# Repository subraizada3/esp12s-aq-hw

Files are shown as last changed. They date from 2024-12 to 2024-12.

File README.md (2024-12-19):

# ESP8266-based air quality sensor master board

This is a board that powers an ESP-12S module with USB-C, and has breakouts for I2C and UART.

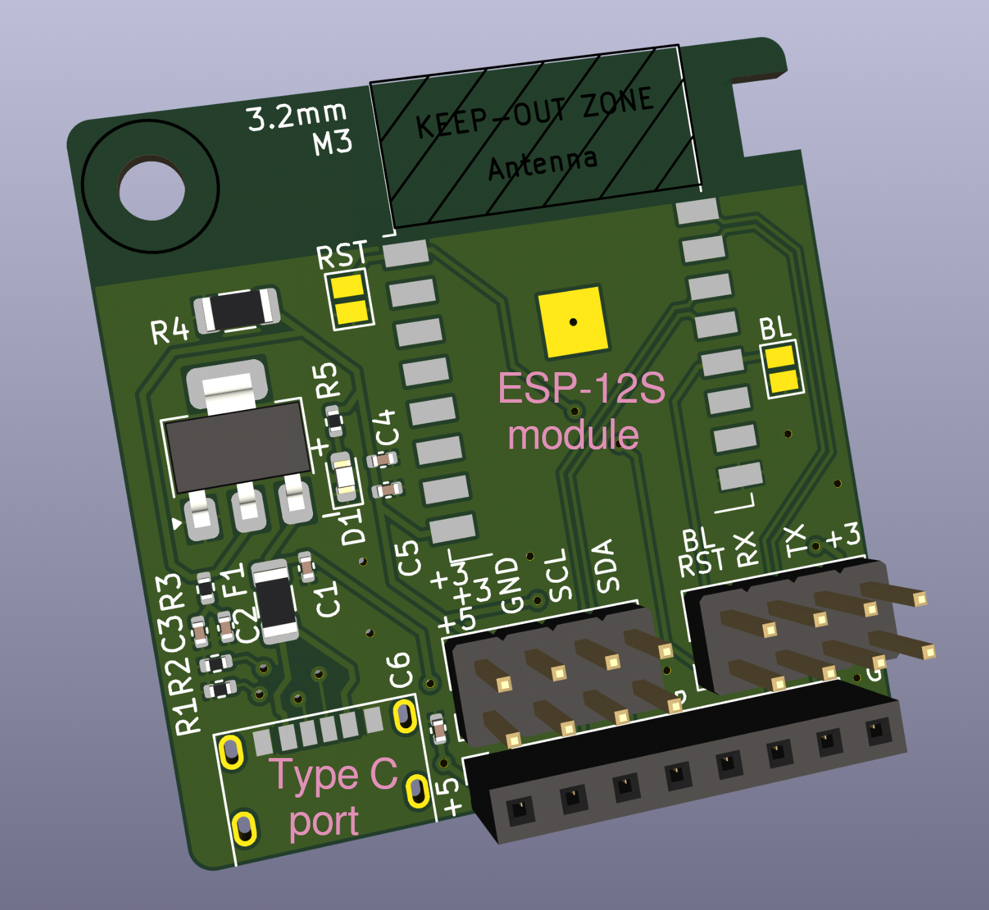
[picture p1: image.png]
image of board


Designed for use as an air quality sensor in combination with:

- Sensirion SCD41 (high accuracy NDIR CO2) - available on an I2C breakout board from various manufacturers
- Sensirion SGP40 (VOC) - available on an I2C breakout board from various manufacturers
- Sensirion SPS30 (particulate matter) - Sensirion manufactures an eval kit that comes with a cable, Sparkfun also sells their own similar kit

Though there's nothing really air-quality-specific here. This is a generic board that powers an ESP-12S and breaks out the I2C/UART pins + 5v/3.3v power to headers. Whatever you connect to those headers is up to you.

See [bom.ods](./bom.ods) for LCSC part numbers for this board (for PCB assembly by JLCPCB).

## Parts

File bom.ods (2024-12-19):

Comment | Qty | Designator | Footprint | Name | LCSC Part # | Extended | Note
USB-C port | 1 | J1 | USB-C-SMD_10P-P1.00-L6.8-W8.9 | TYPE-C-31-M-17 | C283540 | YES | Pins out to in are GND/Vbus/CC
3.3v regulator | 1 | U1 | SOT-223 | AMS1117-3.3 | C6186 | N | Top view, tab facing up, pins L-R are GND/Vout/Vin
ESP-12S | 1 | U2 | QFN-16_EP_16.0x24.0x2.0P | ESP-12S | C82898 | YES
Male header 2x4 | 2 | J2,J4 | Through hole | HDR-TH_8P-P2.54-V-R2-C4-S2.54 | C124386 | YES | 2.54mm, 1.02mm holes in PCB
Female headers 1x8 | 1 | J3 | Through hole | HDR-TH_8P-P2.54-V | C27438 | YES | 2.54mm, 1.02mm holes in PCB
Resistor 5.1k | 2 | R1,R2 | R0402 | 0402WGF5101TCE | C25905 | N | 5mW load, chose 1/16W (62.5mW)
Resistor 1k | 1 | R5 | R0402 | 0402WGF1001TCE | C11702 | N | 2mW load, chose 1/16W (62.5mW)
Resistor 270-330 | 1 | R4 | R1206 | 1206W4F3000T5E | C17887 | N | 40mW load, chose 1/4W (250mW)
Resistor 1 | 1 | R3 | R0402 | 0402WGF100KTCE | C25086 | N | 6mW load, chose 1/16W (62.5mW)
Capacitor 1uF | 2 | C1,C6 | C0402 | CL05A105KA5NQNC | C52923 | N
Capacitor 10uF | 2 | C2,C3,C4 | C0402 | CL05A106MQ5NUNC | C15525 | N
Capacitor 100nF | 1 | C5 | C0402 | CL05B104KO5NNNC | C1525 | N
LED | 1 | D1 | LED_0603 | KT-0603R | C2286 | N | Dot = negative (to GND)
Polyfuse 1A hold | 1 | F1 | F1206 | nSMD100-13.2V | C70081 | YES

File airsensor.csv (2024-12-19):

Reference | Quantity | Value | Footprint | Datasheet
C2 C3 C4 | 3 | 10uF | Capacitor_SMD:C_0402_1005Metric | ~
C5 | 1 | 0.1uF | Capacitor_SMD:C_0402_1005Metric | ~
C1 C6 | 2 | 1uF | Capacitor_SMD:C_0402_1005Metric | ~
D1 | 1 | LED | LED_SMD:LED_0603_1608Metric | ~
F1 | 1 | 1A hold | Fuse:Fuse_1206_3216Metric | ~
H1 H2 | 2 | MountingHole | MountingHole:MountingHole_2.7mm_M2.5 | ~
H3 | 1 | MountingHole | MountingHole:MountingHole_2.2mm_M2 | ~
J1 | 1 | TYPE-C-31-M-17 | footprints:TYPE-C-31-M-17
J2 | 1 | SCD41 CO2 / SGP40 VOC | Connector_PinHeader_2.54mm:PinHeader_2x04_P2.54mm_Vertical | ~
J3 | 1 | SPS30 PM | Connector_PinSocket_2.54mm:PinSocket_1x08_P2.54mm_Vertical | ~
J4 | 1 | TTL Serial | Connector_PinHeader_2.54mm:PinHeader_2x04_P2.54mm_Vertical | ~
JP1 | 1 | RST | Jumper:SolderJumper-2_P1.3mm_Open_Pad1.0x1.5mm | ~
JP2 | 1 | BL | Jumper:SolderJumper-2_P1.3mm_Open_Pad1.0x1.5mm | ~
R1 R2 | 2 | 5.1k | Resistor_SMD:R_0402_1005Metric | ~
R3 | 1 | 1 | Resistor_SMD:R_0402_1005Metric | ~
R4 | 1 | 270-330 | Resistor_SMD:R_1206_3216Metric | ~
R5 | 1 | 1k | Resistor_SMD:R_0402_1005Metric | ~
U1 | 1 | AMS1117-3.3 | Package_TO_SOT_SMD:SOT-223-3_TabPin2 | http://www.advanced-monolithic.com/pdf/ds1117.pdf
U2 | 1 | ESP-12S | footprints:ESP-12S

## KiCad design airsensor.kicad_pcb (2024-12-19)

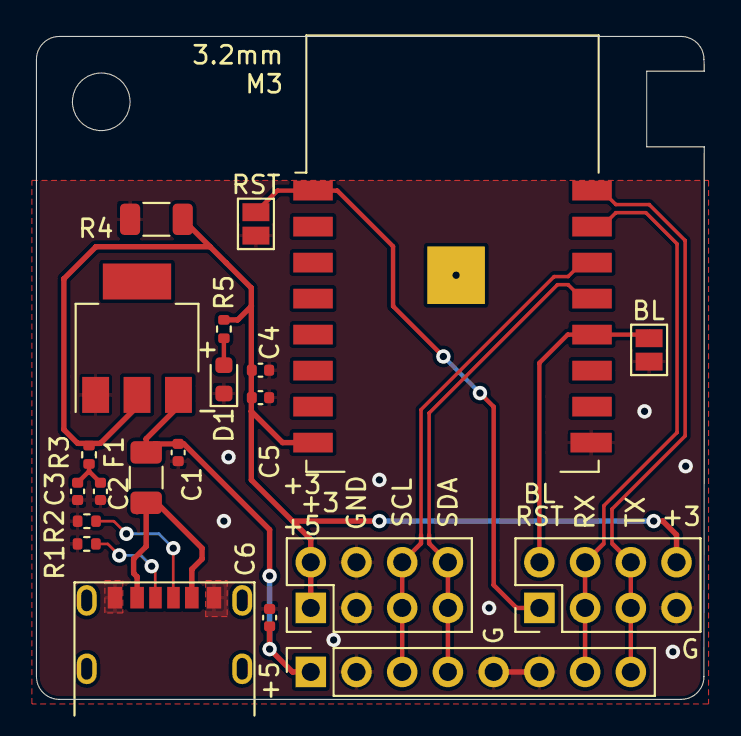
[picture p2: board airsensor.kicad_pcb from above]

Board: 2 copper layers, 37.1 x 36.8 mm, 22 parts (0 on the bottom side), 14 nets.

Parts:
C1, C6: 1uF; C_0402_1005Metric
C2, C3, C4: 10uF; C_0402_1005Metric
C5: 0.1uF; C_0402_1005Metric
D1: LED; LED_0603_1608Metric
F1: 1A hold; Fuse_1206_3216Metric
H1: M3; MountingHole_3.2mm_M3
J1: USB-C; M17
J2: SCD41 CO2 / SGP40 VOC; PinHeader_2x04_P2.54mm_Vertical
J3: SPS30 PM; PinSocket_1x08_P2.54mm_Vertical
J4: TTL Serial; PinHeader_2x04_P2.54mm_Vertical
JP1: RST; SolderJumper-2_P1.3mm_Open_Pad1.0x1.5mm
JP2: BL; SolderJumper-2_P1.3mm_Open_Pad1.0x1.5mm
R1, R2: 5.1k; R_0402_1005Metric
R3: 1; R_0402_1005Metric
R4: 270-330; R_1206_3216Metric
R5: 1k; R_0402_1005Metric
U1: AMS1117-3.3; SOT-223-3_TabPin2
U2: ESP-12S

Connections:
+3V3: C4.1, C5.1, J2.1, J2.2, J4.8, R3.1, R4.2, R5.2, U1.2, U2.8
+5V: C1.1, C6.2, F1.1, J3.1, U1.3
/DTR: J4.2, JP2.1, U2.12
/RST: J4.1, JP1.1, U2.1
/RX: J3.7, J4.3, J4.4, U2.15
/SCL: J2.5, J2.6, J3.3, U2.14
/SDA: J2.7, J2.8, J3.4, U2.13
/TX: J3.8, J4.5, J4.6, U2.16
GND: C1.2, C2.2, C3.2, C4.2, C5.2, C6.1, D1.1, J1.A12, J2.3, J2.4, J3.2, J3.5, J3.6, J4.7, JP1.2, JP2.2, R1.1, R2.1, R4.1, U1.1, U2.9
unnamed: C2.1, C3.1, R3.2
unnamed: D1.2, R5.1
unnamed: F1.2, J1.B9
unnamed: J1.A5, R1.2
unnamed: J1.B5, R2.2

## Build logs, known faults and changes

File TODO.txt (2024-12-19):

Use vias to connect ground plane of voltage regultator to the PCB rear side ground fill

Publish code

Publish 3D model for housing

Update to newer generation Sensirion sensors
